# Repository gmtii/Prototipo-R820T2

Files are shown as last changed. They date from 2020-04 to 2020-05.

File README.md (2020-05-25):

Proyecto 'breakout' de un R820T2 más un QSD para obtener salida IQ directamente a la tarjeta de sonido del PC. La idea es experimentar con el R820T2 y un QSD cuya frecuencia de refencia es 4X a la de demodulación, generada por un Si5351. 

El proyecto contiene:

- Carpeta KICAD: esquemas y PCB directos para generar gerbers.

- Carpeta r820t2: código Arduino para controla el R820T2 y Si5351.

+ Existe un modo consola de comandos serial para controlar los registros del R820T2 directamente y experiemntar.

+ Modo CAT para controlar la frecuencia de sintonía a través de OMNIRIG y el HDSDR por ejemplo.

Los principales aspectos del diseño son:

- El microcontrolador que usemos debe ser 3.3V. 
- El código inicia el R820T2 mediante protocolo I2C. El led, pin 13, y la salida por el puerto serie nos dan indicación del proceso de inicio.
- La parte LOOP consiste en una librería CAT para controlar la frecuencia de sintonía mediante el PC, como por ejemplo el OMNIRIG y el HDSDR.

El principio de hardware es:

- La salida del R820T2 se fija en 5 MHz. El tuner hace un proceso de mezcla de la entrada RF, y la frecuencia de sintonía aparecerá en su salida en esos 5 MHz.
- Se emplea la salida CLKOUT del R820T2, como entrada para un Si5351. Lo ideal es usar un cristal de 25 Mhz en el R820T2.
- Se programa la salida del Si5351 CLK2 a 20 Mhz, que será la entrada del demodulador QSD. Esto realmente es un 'exceso' pero la idea es experimentar con el Si5351 también. Bastaría con instalar un TCXO de 20Mhz al R820T2 para tener exactamente la frecuencia necesaria de demodulación en el QSD, esto es 5 Mhz. Este TCXO sería precisamente el U1. 
- La conversión tiene lugar justo en esos 20MHz/4, esto es, 5 Mhz, justo la salida del R820T2.
- La salida IQ es pues en banda base y directamente aplicable a la tarjeta de sonido del PC. Es recomendable ajustar la entrada a 192 Khz para poder demodular WFM correctamente.
- Con cualquier software que soporte la tarjeta de sonido como entrada, SDR#, o HDSDR, por ejemplo, nos permitirá ver el espectro y demodular la señal resultante.

Modelo 3D de la placa PCB mediante KICAD:

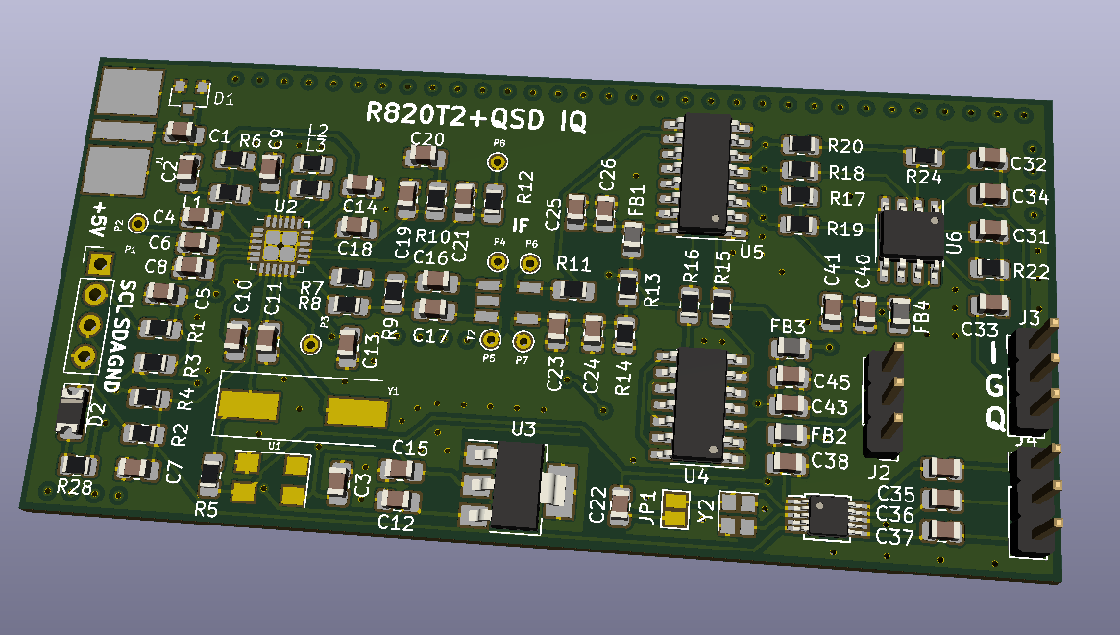
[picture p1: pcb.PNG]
pcb


El proyecto está basado en fuentes como:

Driver del kernel linux del R820T2 ofrecido bajo licencia GPL.
Datasheet del R820T2.
Breakout y fuentes del proyecto del R820T2 de Eric Brombaugh https://github.com/emeb/r820t2/. Licencia MIT.

Esteban EA8DGL estebanjbs < at > gmail.com

Breakout project of an R820T2 plus a QSD to get IQ output directly to the PC sound card. The idea is to experiment with the R820T2 and a QSD whose reference frequency is 4X that of demodulation, generated by a Si5351.

The project contains:

- KICAD folder: diagrams and direct PCBs to generate gerbers.

- r820t2 folder: Arduino code to control the R820T2 and Si5351.

+ There is a serial command console mode to control the registers of the R820T2 directly and experiment.

+ CAT mode to control the tuning frequency through OMNIRIG and HDSDR for example.

The main aspects of the design are:

- The microcontroller that we use must be 3.3V.
- The code starts the R820T2 using the I2C protocol. The led, pin 13, and the output through the serial port give us an indication of the startup process.
- The LOOP part consists of a CAT library to control the tuning frequency through the PC, such as OMNIRIG and HDSDR.

The hardware principle is:

- The R820T2's output is fixed at 5 MHz. The tuner does a process of mixing the RF input, and the tuning frequency will appear at its output at those 5 MHz.
- The CLKOUT output of the R820T2 is used as input for a Si5351. Ideally, use a 25Mhz crystal on the R820T2.
- The output of Si5351 CLK2 is programmed at 20 Mhz, which will be the input of the QSD demodulator. This really is 'overkill' but the idea is to experiment with the Si5351 as well. It would be enough to install a 20Mhz TCXO to the R820T2 to have exactly the necessary demodulation frequency in the QSD, this is 5 Mhz. This TCXO would be precisely U1.
- The conversion takes place right at those 20MHz / 4, that is, 5Mhz, just the output of the R820T2.
- The IQ output is thus in baseband and directly applicable to the PC sound card. It is recommended to set the input to 192 Khz in order to demodulate WFM correctly.
- With any software that supports the sound card as input, SDR #, or HDSDR, for example, it will allow us to see the spectrum and demodulate the resulting signal.

3D model of the PCB board using KICAD:

! [pcb] (pcb.PNG)

The project is based on sources such as:

R820T2 Linux kernel driver offered under the GPL license.
Datasheet of the R820T2.
Breakout and sources for Eric Brombaugh's R820T2 project https://github.com/emeb/r820t2/. MIT license.

Esteban EA8DGL estebanjbs <at> gmail.com

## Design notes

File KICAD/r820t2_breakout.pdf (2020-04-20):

r820t2_breakout

Id Designator | Package | Quantity
1 REF** | SolderWirePad_1x01_Drill0.8mm | 1
2 J4,J2 | PinHeader_1x03_P2.54mm_Vertical | 2
3 Y2 | Crystal_SMD_2520-4Pin_2.5x2.0mm | 1
4 JP1 | SolderJumper-2_P1.3mm_Open_Pad1.0x1.5mm | 1
5 C38,C22,C43,C40,C37,C36,C35,C25,C23 C_0805_2012Metric | 9
6 C4,C9,C8,C13,C21,C18,C17,C16,C14,C3 C_0805_2012Metric_Pad1.15x1.40mm_HandSolder | 10
7 C6 | C_0805_2012Metric_Pad1.15x1.40mm_HandSolder | 1
8 C2,C19 | C_0805_2012Metric_Pad1.15x1.40mm_HandSolder | 2
9 C1 | C_0805_2012Metric_Pad1.15x1.40mm_HandSolder | 1
10 R22,R26,R25 | R_0805_2012Metric | 3
11 RV1 | Potentiometer_Bourns_3214W_Vertical | 1
12 J3 | PinHeader_1x03_P2.54mm_Vertical | 1
13 U5 | SOIC-16_3.9x9.9mm_P1.27mm | 1
14 R24 | R_0805_2012Metric | 1
15 R15,R16 | R_0805_2012Metric | 2
16 U4 | SOIC-14_3.9x8.7mm_P1.27mm | 1
17 R11,R5 | R_0805_2012Metric_Pad1.15x1.40mm_HandSolder | 2
18 P4,P2,P3,P5,P6,P7,P8 | PINTST | 7
19 C11,C7,C5,C10 | C_0805_2012Metric_Pad1.15x1.40mm_HandSolder | 4
20 R4,R3 | R_0805_2012Metric_Pad1.15x1.40mm_HandSolder | 2
21 R2,R1,R8,R7 | R_0805_2012Metric_Pad1.15x1.40mm_HandSolder | 4
22 U7 | MSOP-10_3x3mm_P0.5mm | 1
23 U6 | SOIC-8_3.9x4.9mm_P1.27mm | 1
24 R28 | R_0805_2012Metric | 1
25 R20,R19,R18,R17 | R_0805_2012Metric | 4
26 R14,R13 | R_0805_2012Metric | 2
27 R12 | R_0805_2012Metric_Pad1.15x1.40mm_HandSolder | 1
28 R10 | R_0805_2012Metric_Pad1.15x1.40mm_HandSolder | 1
29 R9 | R_0805_2012Metric_Pad1.15x1.40mm_HandSolder | 1
30 R6 | R_0805_2012Metric_Pad1.15x1.40mm_HandSolder | 1
31 L3,L2 | R_0805_2012Metric_Pad1.15x1.40mm_HandSolder | 2
32 L1 | R_0805_2012Metric_Pad1.15x1.40mm_HandSolder | 1
33 FB4,FB3,FB2,FB1 | L_0805_2012Metric | 4
34 D2 | D_1206_3216Metric | 1
35 C45,C41,C26,C24 | C_0805_2012Metric | 4
36 C34,C33 | C_0805_2012Metric | 2
37 C32,C31 | C_0805_2012Metric | 2
38 C30,C29,C28,C27 | C_0805_2012Metric | 4
39 C20 | C_0805_2012Metric_Pad1.15x1.40mm_HandSolder | 1
40 C15,C12 | C_0805_2012Metric_Pad1.15x1.40mm_HandSolder | 2
41 D1 | SOT-23 | 1
42 P1 | Pin_Header_Straight_1x04_Pitch2.54mm | 1
43 T2 | Pulse_SMD_Balun | 1
44 U1 | Crystal_SMD_Abracon_ABM3C-4pin_5.0x3.2mm | 1
45 U3 | SOT-223 | 1
46 Y1 | XTAL 2520 SMD 25 Mhz | 1
47 J1 | SMA_END | 1
48 U2 | QFN-24-1EP_4x4mm_Pitch0.5mm_extended_pad | 1

r820t2_breakout

Designation | Supplier and ref
SolderWirePad_1x01_Drill0.8mm
CLK Source
Crystal_GND24
SolderJumper_2_Open
100nF
0.1uf
1uf
330pf
0.01uf
10k
5k
Conn_01x03_Male
SN74CBT3253
8.2k
0
74HC74
0
CONN_01X01
27pf
4k7
220
Si5351A-B-GT
LT6234
512
100
5.6k
10k
1k8
DNI
10
150nh
8.2nH
Ferrite_Bead
LED
4.7uF
2.2uF
330p
33nF
6800pf
10uf
BAV99
CONN_01X04
TRANSFO4
TWEAALSANF-28.800000
LD1117S33CTR
25MHz
SMA
R820T2

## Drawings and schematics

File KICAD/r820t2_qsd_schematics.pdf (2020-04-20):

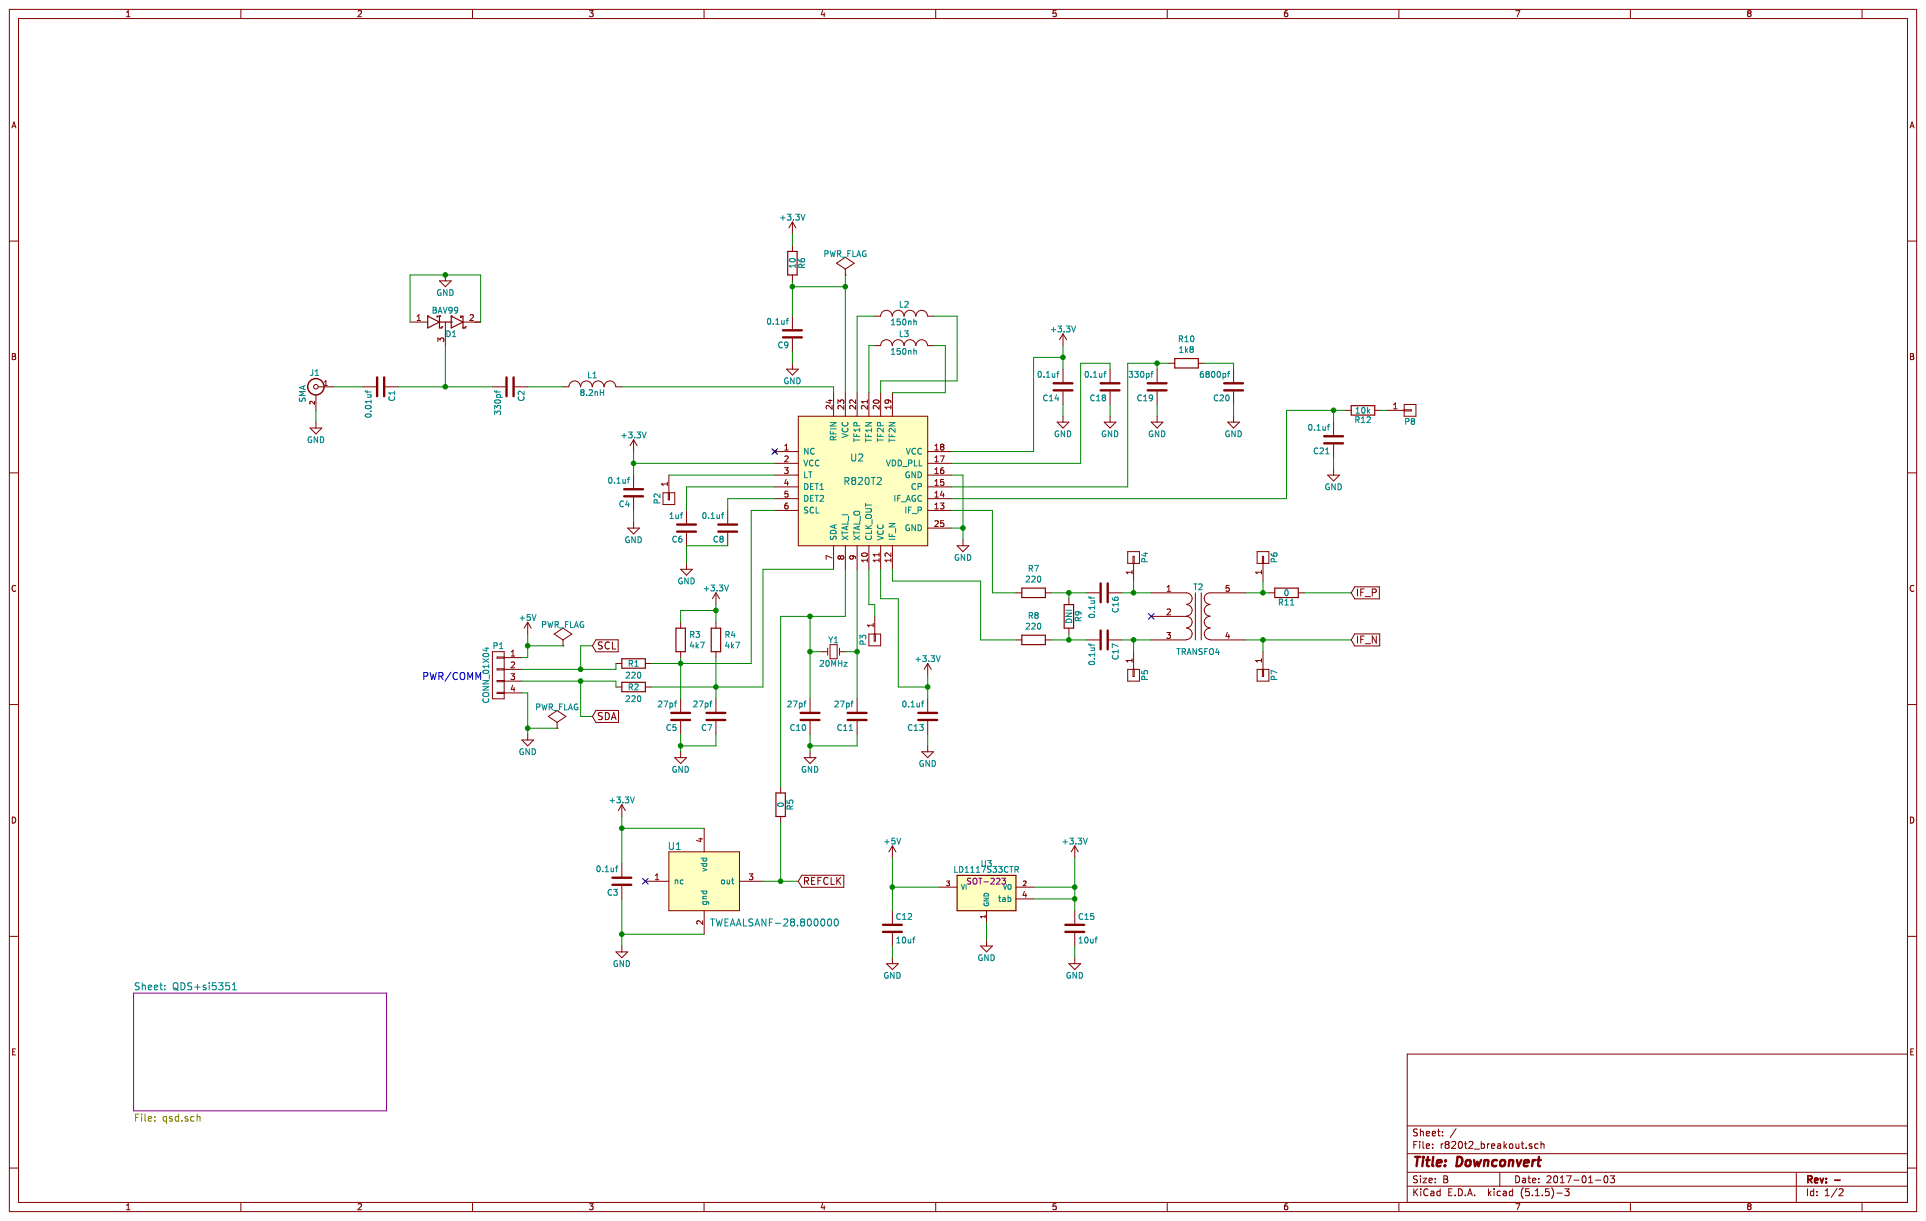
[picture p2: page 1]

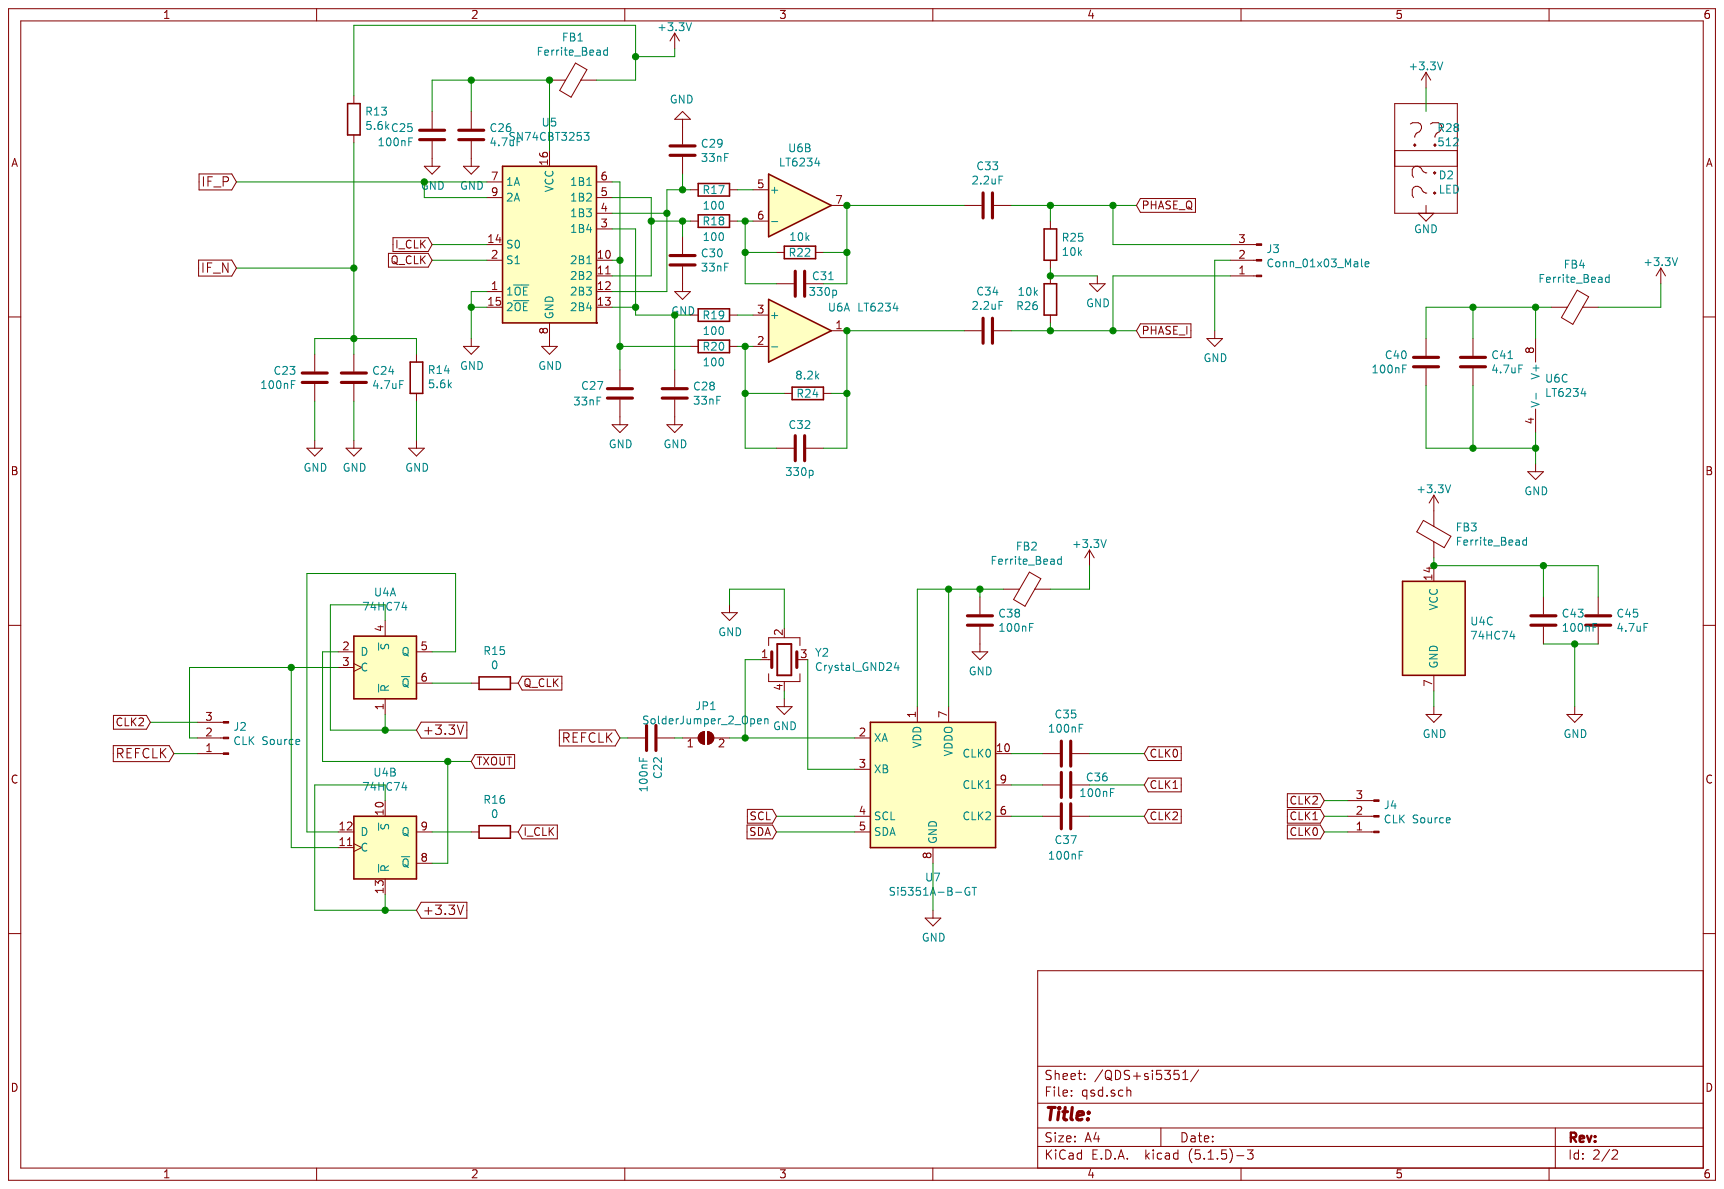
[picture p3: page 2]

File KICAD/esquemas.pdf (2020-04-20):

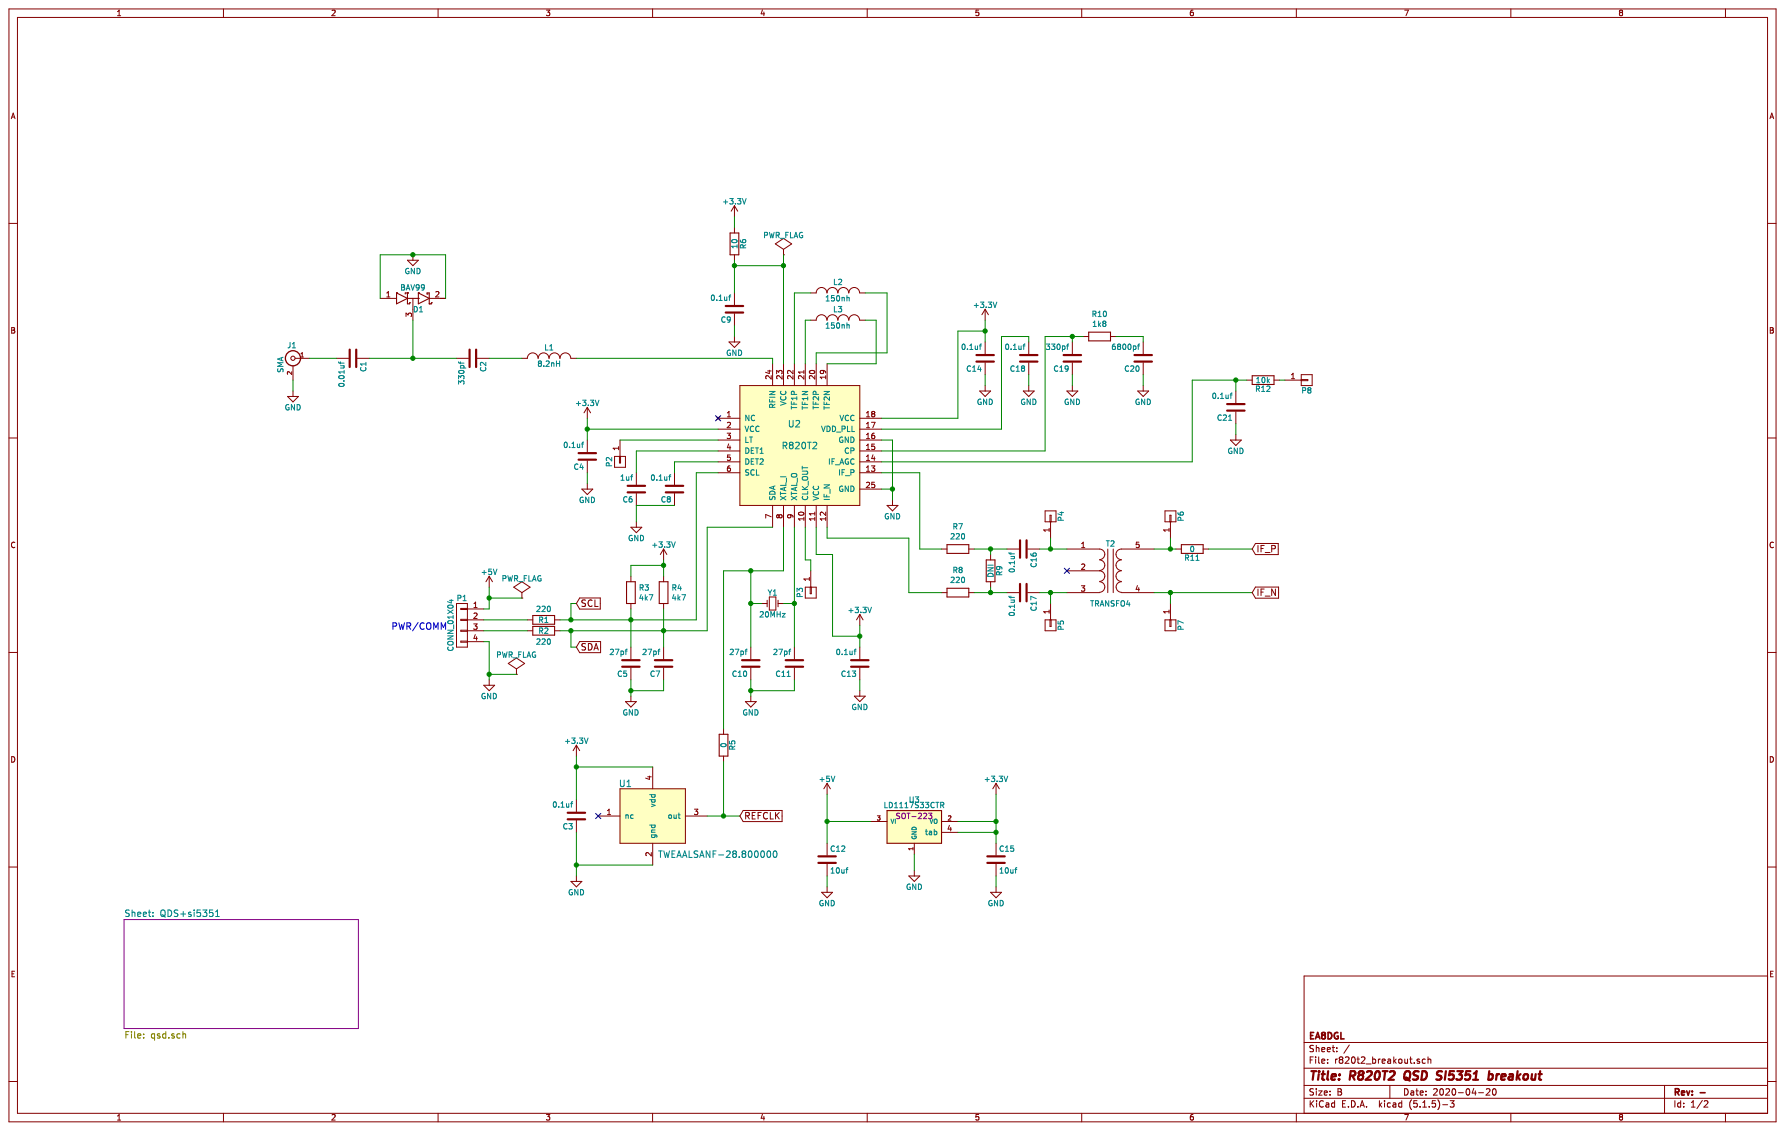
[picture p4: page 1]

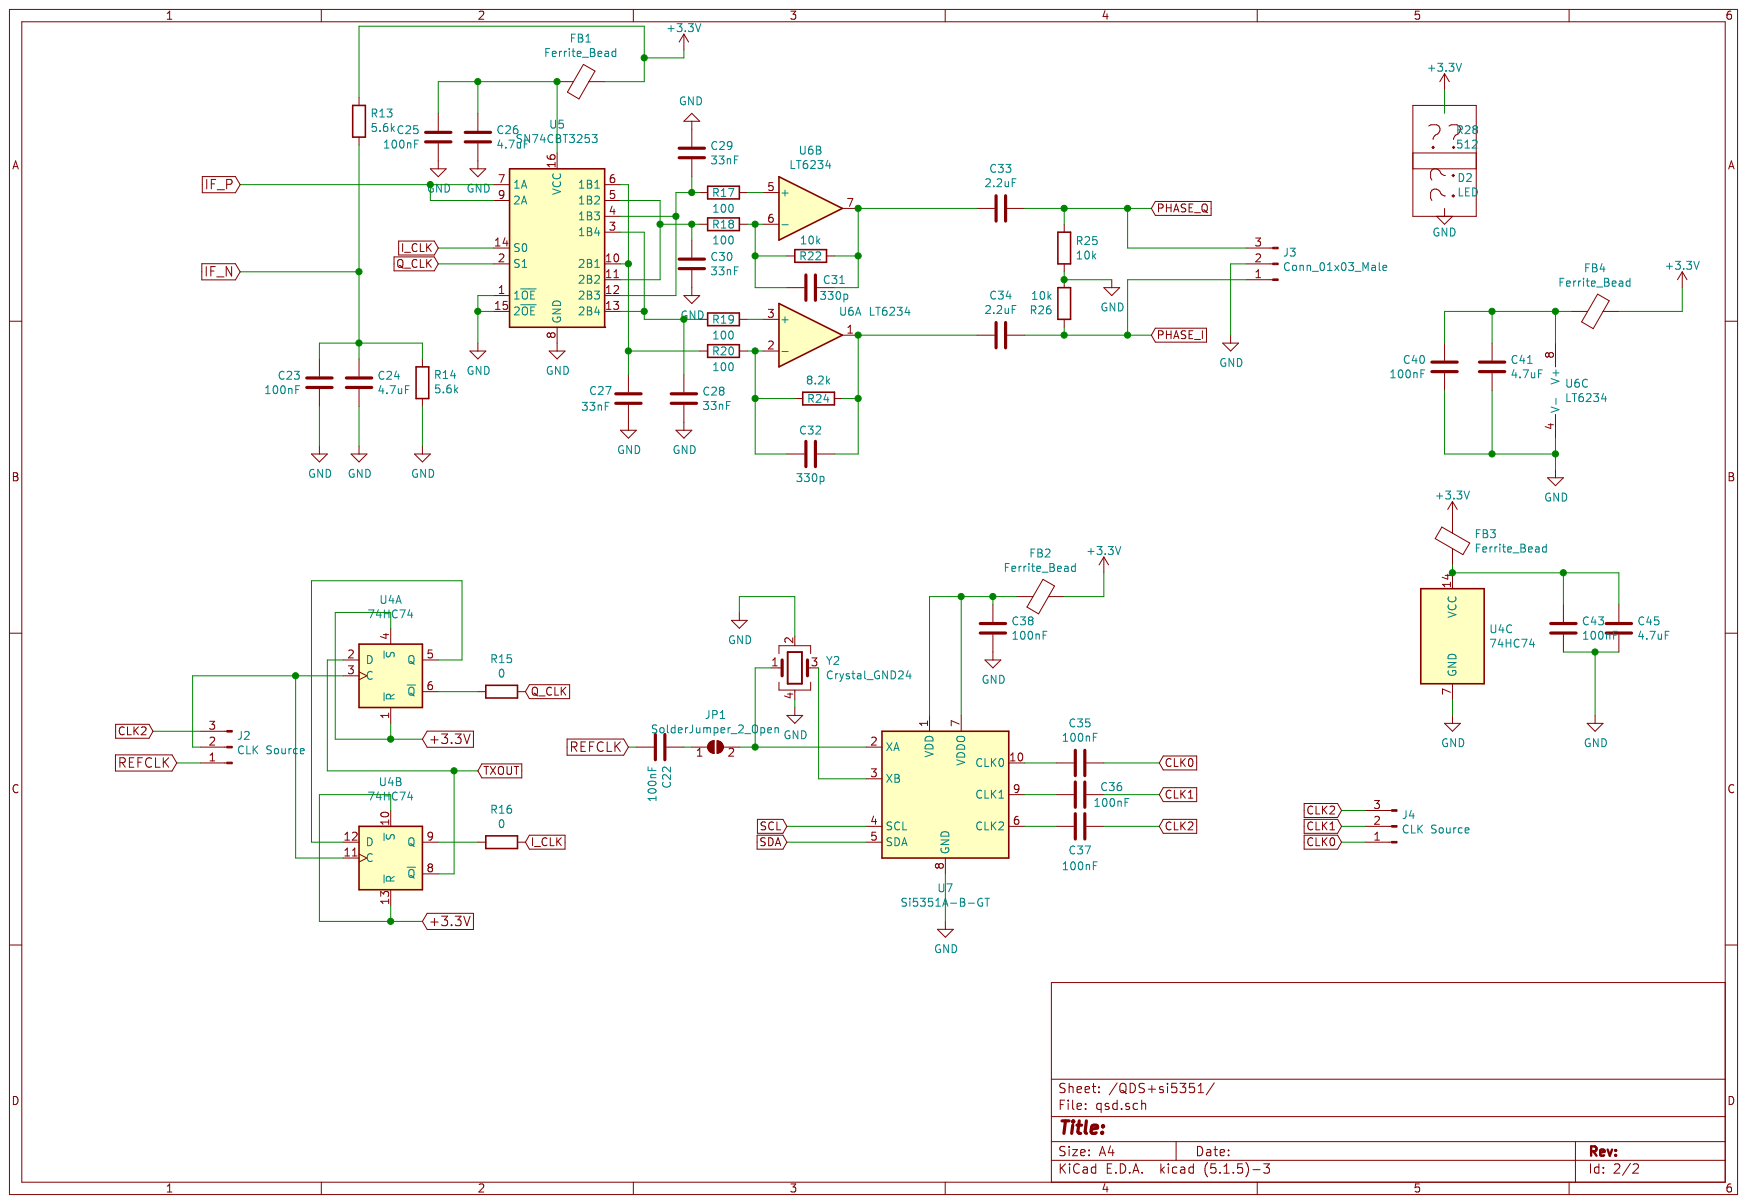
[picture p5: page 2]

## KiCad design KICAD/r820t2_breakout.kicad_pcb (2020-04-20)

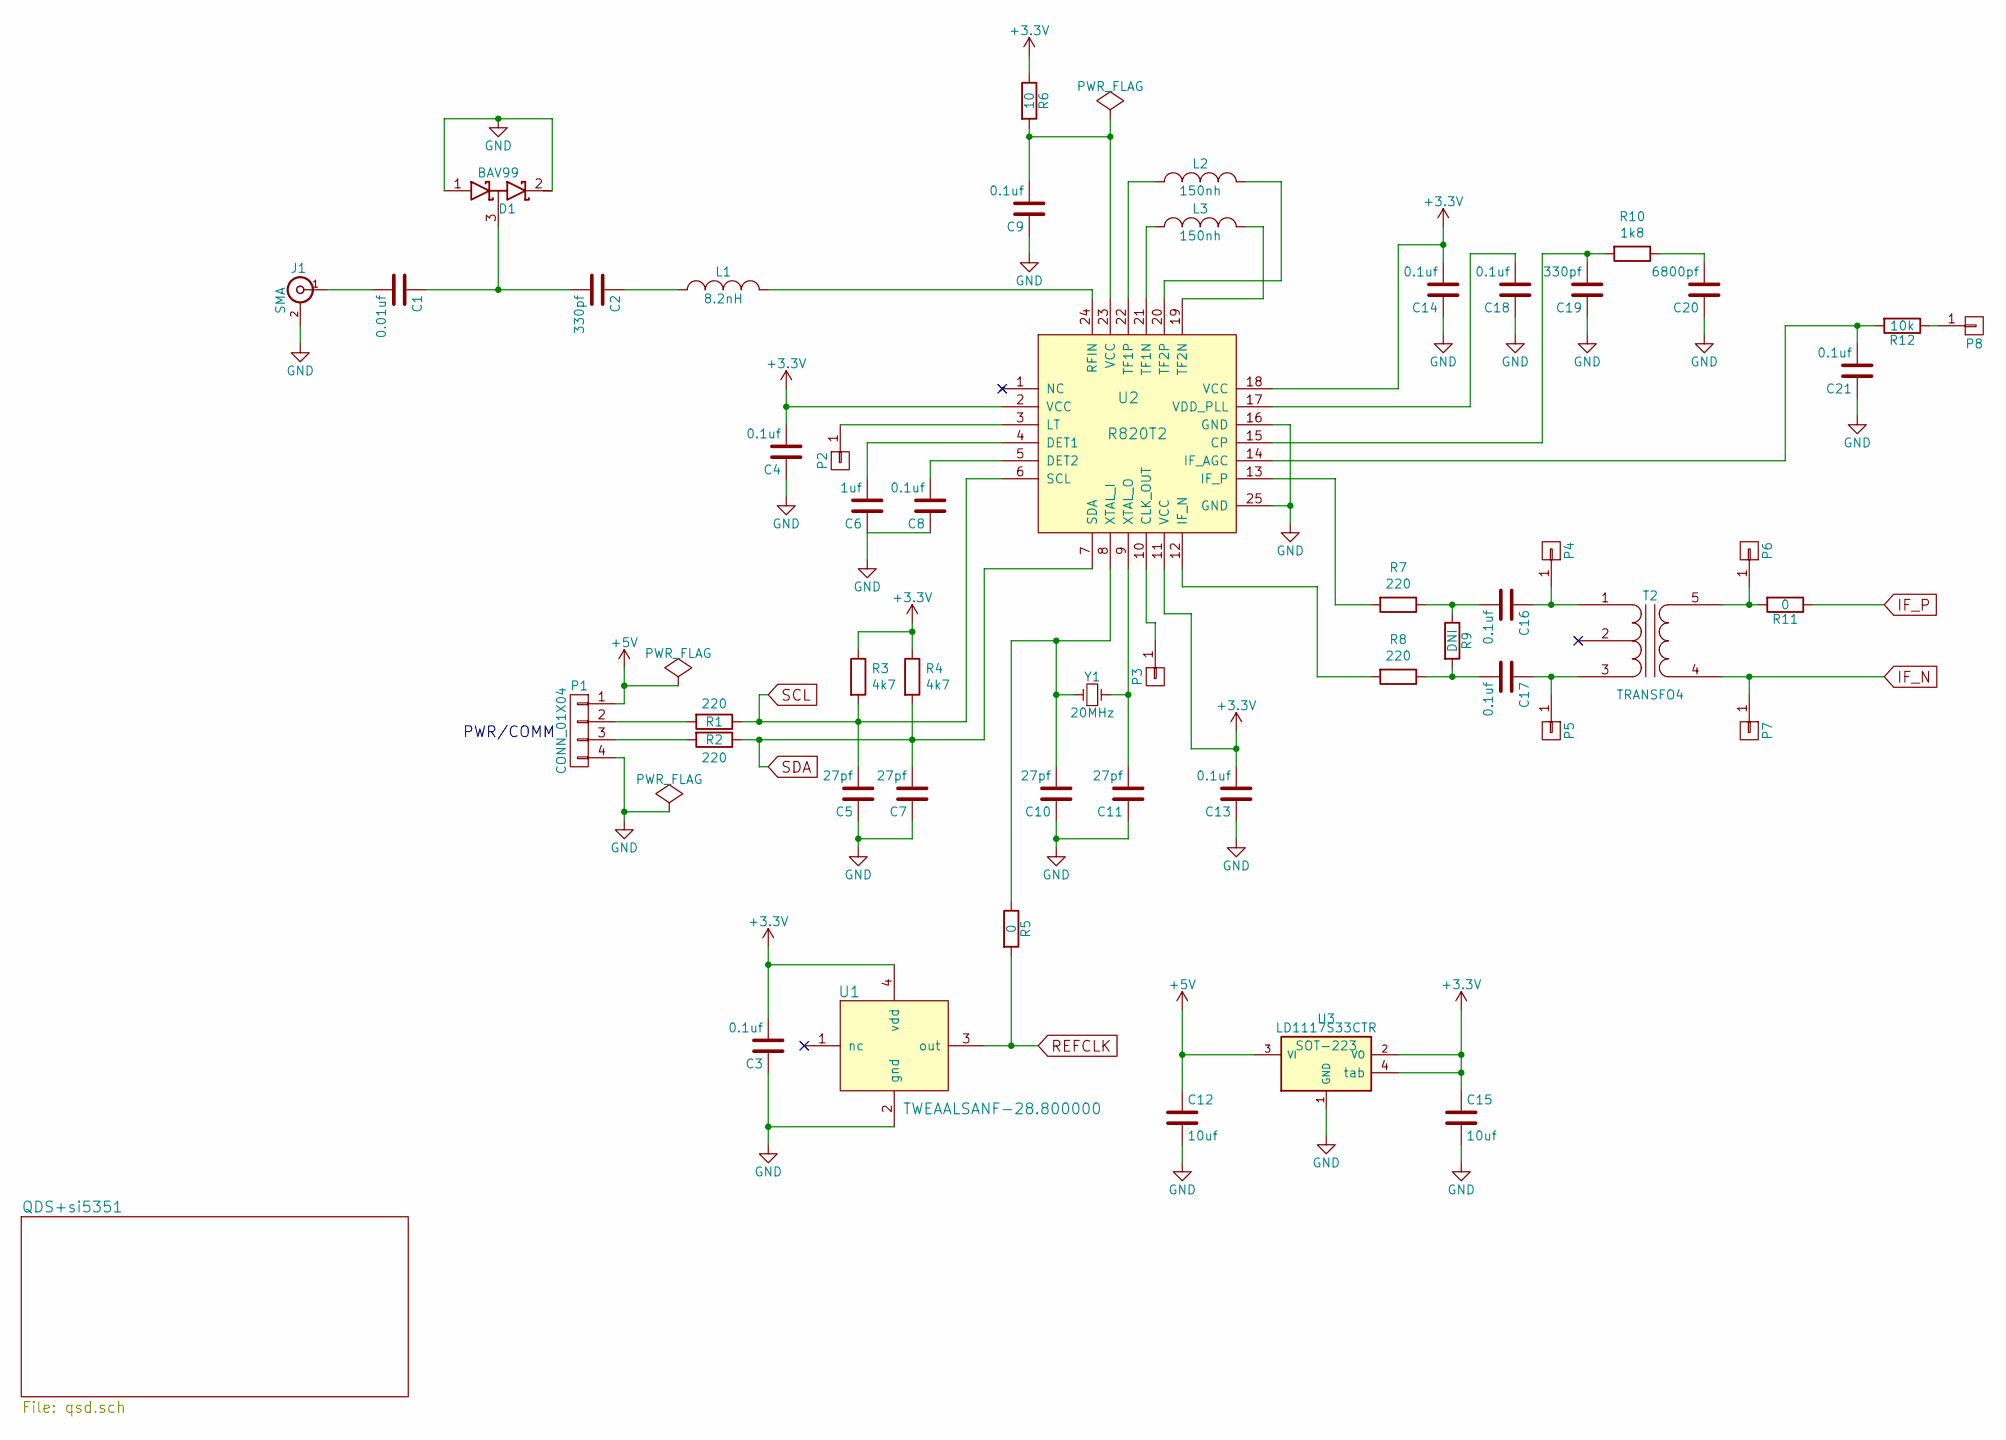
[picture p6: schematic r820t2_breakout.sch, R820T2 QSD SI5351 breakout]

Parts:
C1: 0.01uf; C_0805_2012Metric_Pad1.15x1.40mm_HandSolder
C2, C19: 330pf; C_0805_2012Metric_Pad1.15x1.40mm_HandSolder
C3, C4, C8, C9, C13, C14, C16, C17, C18, C21: 0.1uf; C_0805_2012Metric_Pad1.15x1.40mm_HandSolder
C5, C7, C10, C11: 27pf; C_0805_2012Metric_Pad1.15x1.40mm_HandSolder
C6: 1uf; C_0805_2012Metric_Pad1.15x1.40mm_HandSolder
C12, C15: 10uf; C_0805_2012Metric_Pad1.15x1.40mm_HandSolder
C20: 6800pf; C_0805_2012Metric_Pad1.15x1.40mm_HandSolder
D1: BAV99; SOT-23
J1: SMA; SMA_END
L1: 8.2nH; R_0805_2012Metric_Pad1.15x1.40mm_HandSolder
L2, L3: 150nh; R_0805_2012Metric_Pad1.15x1.40mm_HandSolder
P1: CONN_01X04; Pin_Header_Straight_1x04_Pitch2.54mm
P2, P3, P4, P5, P6, P7, P8: CONN_01X01; PINTST
R1, R2, R7, R8: 220; R_0805_2012Metric_Pad1.15x1.40mm_HandSolder
R3, R4: 4k7; R_0805_2012Metric_Pad1.15x1.40mm_HandSolder
R5, R11: 0; R_0805_2012Metric_Pad1.15x1.40mm_HandSolder
R6: 10; R_0805_2012Metric_Pad1.15x1.40mm_HandSolder
R9: DNI; R_0805_2012Metric_Pad1.15x1.40mm_HandSolder
R10: 1k8; R_0805_2012Metric_Pad1.15x1.40mm_HandSolder
R12: 10k; R_0805_2012Metric_Pad1.15x1.40mm_HandSolder
T2: TRANSFO4; Pulse_SMD_Balun
U1: TWEAALSANF-28.800000; Crystal_SMD_Abracon_ABM3C-4pin_5.0x3.2mm
U2: R820T2; QFN-24-1EP_4x4mm_P0.5mm_EP2.65x2.65mm_ThermalVias
U3: LD1117S33CTR; SOT-223
Y1: 20MHz; Crystal_SMD_HC49-SD

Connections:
+3V3: C3.2, C4.2, C13.2, C14.2, C15.1, R3.1, R4.1, R6.1, U1.4 (vdd), U2.2 (VCC), U2.11 (VCC), U2.18 (VCC), U3.2 (VO), U3.4 (tab); also elsewhere on the board
+5V: C12.1, P1.1, U3.3 (VI)
GND: C3.1, C4.1, C5.1, C6.1, C7.1, C8.1, C9.1, C10.1, C11.1, C12.2, C13.1, C14.1, C15.2, C18.1, C19.1, C20.1, C21.1, D1.1 (A), D1.2 (K), J1.2 (Ext), P1.4, U1.2 (gnd), U2.16 (GND), U2.25 (GND), U3.1 (GND); also elsewhere on the board
IF_N: P7.1, T2.4 (S1); also elsewhere on the board
IF_P: R11.1; also elsewhere on the board
unnamed: C1.1, C2.2, D1.3 (common)
unnamed: C1.2, J1.1 (In)
unnamed: C2.1, L1.1
unnamed: C6.2, U2.4 (DET1)
unnamed: C8.2, U2.5 (DET2)
unnamed: C9.2, R6.2, U2.23 (VCC)
unnamed: C10.2, R5.1, U2.8 (XTAL_I), Y1.1
unnamed: C11.2, U2.9 (XTAL_O), Y1.2
unnamed: C16.1, P4.1, T2.1 (PR1)
unnamed: C16.2, R7.1, R9.1
unnamed: C17.1, P5.1, T2.3 (PR2)
unnamed: C17.2, R8.1, R9.2
unnamed: C18.2, U2.17 (VDD_PLL)
unnamed: C19.2, R10.2, U2.15 (CP)
unnamed: C20.2, R10.1
unnamed: C21.2, R12.2, U2.14 (IF_AGC)
unnamed: L1.2, U2.24 (RFIN)
unnamed: L2.1, U2.20 (TF2P)
unnamed: L2.2, U2.22 (TF1P)
unnamed: L3.1, U2.19 (TF2N)
unnamed: L3.2, U2.21 (TF1N)
unnamed: P1.2, R1.2
unnamed: P1.3, R2.2
unnamed: P2.1, U2.3 (LT)
unnamed: P3.1, U2.10 (CLK_OUT)
unnamed: P6.1, R11.2, T2.5 (S2)
unnamed: P8.1, R12.1
unnamed: R7.2, U2.13 (IF_P)
unnamed: R8.2, U2.12 (IF_N)
REFCLK: R5.2, U1.3 (out); also elsewhere on the board
SCL: C5.2, R1.1, R3.2, U2.6 (SCL); also elsewhere on the board
SDA: C7.2, R2.1, R4.2, U2.7 (SDA); also elsewhere on the board

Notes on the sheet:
PWR/COMM

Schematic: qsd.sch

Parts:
C22, C23, C25, C35, C36, C37, C38, C40, C43: 100nF; C_0805_2012Metric
C24, C26, C41, C45: 4.7uF; C_0805_2012Metric
C27, C28, C29, C30: 33nF; C_0805_2012Metric
C31, C32: 330p; C_0805_2012Metric
C33, C34: 2.2uF; C_0805_2012Metric
D2: LED; D_1206_3216Metric
FB1, FB2, FB3, FB4: Ferrite_Bead; L_0805_2012Metric
J2, J4: CLK Source; PinHeader_1x03_P2.54mm_Vertical
J3: Conn_01x03_Male; PinHeader_1x03_P2.54mm_Vertical
JP1: SolderJumper_2_Open; SolderJumper-2_P1.3mm_Open_Pad1.0x1.5mm
R13, R14: 5.6k; R_0805_2012Metric
R15, R16: 0; R_0805_2012Metric
R17, R18, R19, R20: 100; R_0805_2012Metric
R22, R25, R26: 10k; R_0805_2012Metric
R24: 8.2k; R_0805_2012Metric
R28: 512; R_0805_2012Metric
U4: 74HC74; SOIC-14_3.9x8.7mm_P1.27mm
U5: SN74CBT3253; SOIC-16_3.9x9.9mm_P1.27mm
U6: LT6234; SOIC-8_3.9x4.9mm_P1.27mm
U7: Si5351A-B-GT; MSOP-10_3x3mm_P0.5mm
Y2: Crystal_GND24; Crystal_SMD_2520-4Pin_2.5x2.0mm

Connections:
+3.3V: U4.1 (~R), U4.4 (~S), U4.10 (~S), U4.13 (~R)
+3V3: FB1.1, FB2.1, FB3.1, FB4.1, R13.2, R28.1; also elsewhere on the board
CLK0: C35.1, J4.1
CLK1: C36.1, J4.2
CLK2: C37.1, J2.3, J4.3
GND: C23.2, C24.2, C25.2, C26.2, C27.2, C28.2, C29.1, C30.2, C38.2, C40.2, C41.2, C43.2, C45.2, D2.1, J3.2, R14.1, R25.2, R26.2, U4.7 (GND), U5.1 (1~OE), U5.8 (GND), U5.15 (2~OE), U6.4 (V-), U7.8 (GND), Y2.2, Y2.4; also elsewhere on the board
IF_N: C23.1, C24.1, R13.1, R14.2; also elsewhere on the board
IF_P: U5.7 (1A), U5.9 (2A); also elsewhere on the board
I_CLK: R16.1, U5.14 (S0)
unnamed: C22.1, JP1.1 (A)
unnamed: C25.1, C26.1, FB1.2, U5.16 (VCC)
unnamed: C27.1, R20.2, U5.6 (1B1), U5.10 (2B1)
unnamed: C28.1, R19.2, U5.3 (1B4), U5.13 (2B4)
unnamed: C29.2, R17.2, U5.4 (1B3), U5.12 (2B3)
unnamed: C30.1, R18.2, U5.5 (1B2), U5.11 (2B2)
unnamed: C31.1, C33.2, R22.1, U6.7
unnamed: C31.2, R18.1, R22.2, U6.6 (-)
unnamed: C32.1, C34.2, R24.1, U6.1
unnamed: C32.2, R20.1, R24.2, U6.2 (-)
unnamed: C35.2, U7.10 (CLK0)
unnamed: C36.2, U7.9 (CLK1)
unnamed: C37.2, U7.6 (CLK2)
unnamed: C38.1, FB2.2, U7.1 (VDD), U7.7 (VDDO)
unnamed: C40.1, C41.1, FB4.2, U6.8 (V+)
unnamed: C43.1, C45.1, FB3.2, U4.14 (VCC)
unnamed: D2.2, R28.2
unnamed: J2.2, U4.3 (C), U4.11 (C)
unnamed: JP1.2 (B), U7.2 (XA), Y2.1
unnamed: R15.2, U4.6 (~Q)
unnamed: R16.2, U4.9 (Q)
unnamed: R17.1, U6.5 (+)
unnamed: R19.1, U6.3 (+)
unnamed: U4.5 (Q), U4.12 (D)
unnamed: U7.3 (XB), Y2.3
PHASE_I: C34.1, J3.1, R26.1
PHASE_Q: C33.1, J3.3, R25.1
Q_CLK: R15.1, U5.2 (S1)
REFCLK: C22.2, J2.1; also elsewhere on the board
SCL: U7.4 (SCL); also elsewhere on the board
SDA: U7.5 (SDA); also elsewhere on the board
TXOUT: U4.2 (D), U4.8 (~Q)

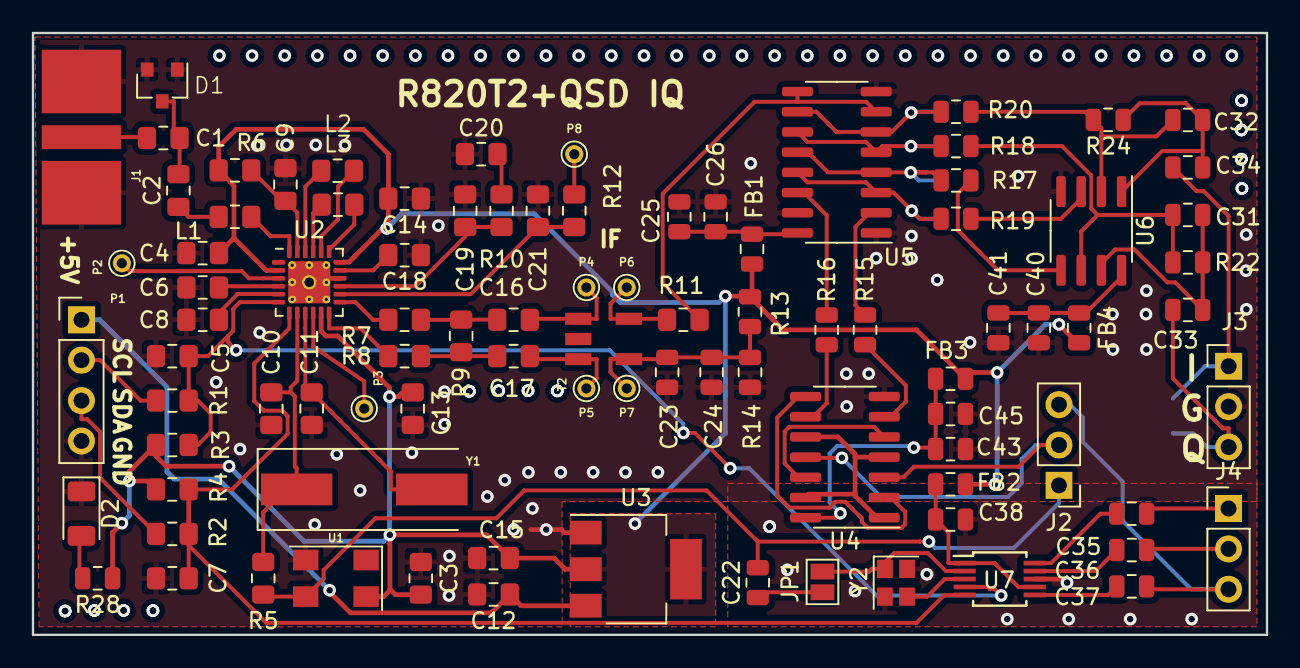
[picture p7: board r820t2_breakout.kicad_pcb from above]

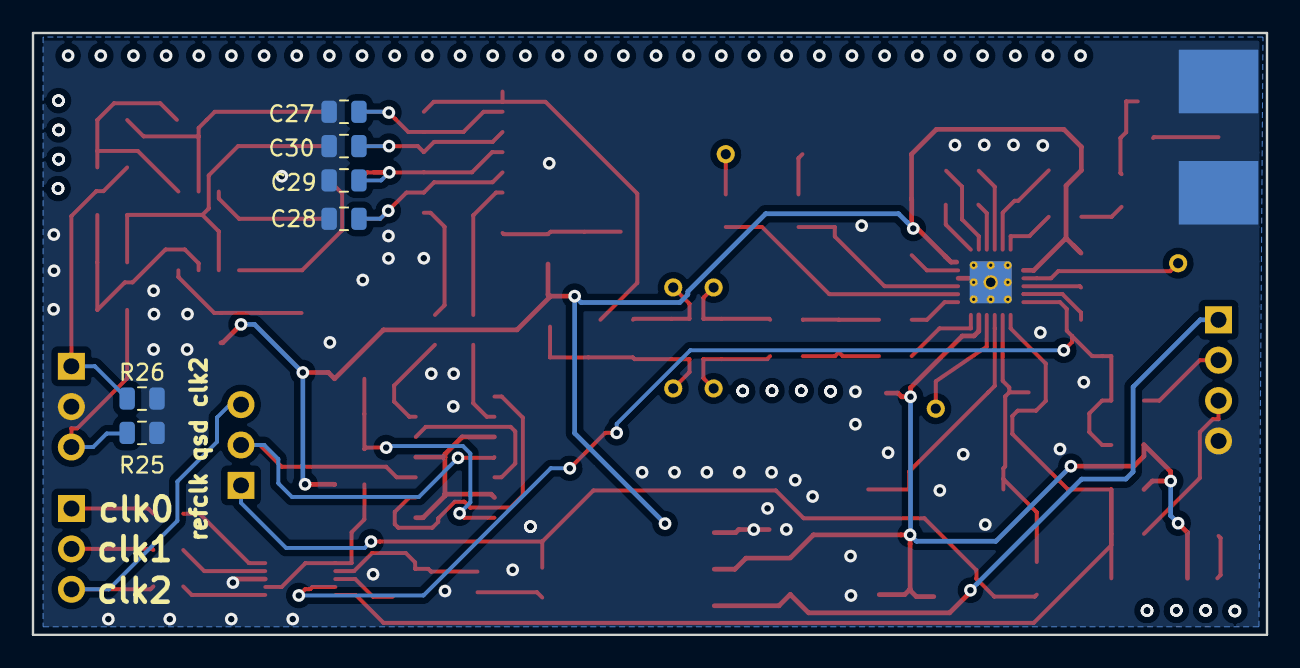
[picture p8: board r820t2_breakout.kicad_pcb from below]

Board: 2 copper layers, 77.6 x 37.8 mm, 99 parts (6 on the bottom side), 71 nets.

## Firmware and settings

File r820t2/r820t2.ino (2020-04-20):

/* 
	Prototipo R820T2+QSD con Si5351 
	Basado en drivers
    Copyright (C) 2020 EA8DGL

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
	*/


#include <Arduino.h>
#include <Wire.h>

#include "si5351.h"
#include "serial_cmd.h"

const int ledPin = 13;


#define SI5351_XTAL_FREQ  25000000

uint64_t target_freq = 2000000000ULL;
int32_t cal_factor = 10000;


Si5351 si5351;

void setup() {

  byte error;
  pinMode(ledPin, OUTPUT);

  Serial.begin(9600);
  Serial.flush();

  delay(2000);

  Wire.begin();

  Wire.beginTransmission(0x1A);
  error = Wire.endTransmission();

  if (error == 0)
  {
    Serial.println("I2C device found at address 0x1A");

    digitalWrite(ledPin, HIGH);
    delay(250);
    digitalWrite(ledPin, LOW);
    delay(250);
  }

  Wire.beginTransmission(0x60);
  error = Wire.endTransmission();

  if (error == 0)
  {
    Serial.println("I2C device found at address 0x60");

    digitalWrite(ledPin, HIGH);
    delay(250);
    digitalWrite(ledPin, LOW);
    delay(250);
    digitalWrite(ledPin, HIGH);
  }

  R820T2_init();

  delay(500);

  // Start on target frequency
  si5351.set_correction(cal_factor, SI5351_PLL_INPUT_XO);
  si5351.set_pll(SI5351_PLL_FIXED, SI5351_PLLA);


  si5351.init(SI5351_CRYSTAL_LOAD_0PF, SI5351_XTAL_FREQ, 0);
  si5351.set_freq(target_freq, SI5351_CLK2);
  si5351.output_enable(SI5351_CLK2, 1);

  si5351.update_status();

  delay(500);

  // I had near 0.7 Vpp CLKIN -> LOS=1 so it need to repeat init sequence.

  si5351.init(SI5351_CRYSTAL_LOAD_0PF, SI5351_XTAL_FREQ, 0);
  si5351.set_freq(target_freq, SI5351_CLK2);
  si5351.output_enable(SI5351_CLK2, 1);
  
  si5351.output_enable(SI5351_CLK0, 0);
  si5351.output_enable(SI5351_CLK1, 0);

  si5351.update_status();

  //tft.fillScreen(TFT_BLACK);
  //tft.setTextColor(TFT_WHITE, TFT_BLACK);
  //tft.setTextFont(3);

}

static void flush_input(void)
{
  while (Serial.available() > 0)
    Serial.read();
}

// ;Loop to check for FT 575 Yaesu compatible CAT commands.

void loop()
{
  // Serial_CMD();  // Uncomment to enable R820T2 console.
  checkCAT(); 

}

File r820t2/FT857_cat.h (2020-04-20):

/**
 * The CAT protocol is used by many radios to provide remote control to comptuers through
 * the serial port.
 * 
 * This is very much a work in progress. Parts of this code have been liberally
 * borrowed from other GPLicensed works like hamlib.
 * 
 * WARNING : This is an unstable version and it has worked with fldigi, 
 * it gives time out error with WSJTX 1.8.0  
 */


/** 
 *  The second set of 16 pins on the Raduino's bottom connector are have the three clock outputs and the digital lines to control the rig.
 *  This assignment is as follows :
 *    Pin   1   2    3    4    5    6    7    8    9    10   11   12   13   14   15   16
 *         GND +5V CLK0  GND  GND  CLK1 GND  GND  CLK2  GND  D2   D3   D4   D5   D6   D7  
 *  These too are flexible with what you may do with them, for the Raduino, we use them to :
 *  - TX_RX line : Switches between Transmit and Receive after sensing the PTT or the morse keyer
 *  - CW_KEY line : turns on the carrier for CW
 */

#define TX_RX (7)
#define CW_TONE (6)
#define TX_LPF_A (5)
#define TX_LPF_B (4)
#define TX_LPF_C (3)
#define CW_KEY (2)

/**
 * These are the indices where these user changable settinngs are stored  in the EEPROM
 */
#define MASTER_CAL 0
#define LSB_CAL 4
#define USB_CAL 8
#define SIDE_TONE 12
//these are ids of the vfos as well as their offset into the eeprom storage, don't change these 'magic' values
#define VFO_A 16
#define VFO_B 20
#define CW_SIDETONE 24
#define CW_SPEED 28

//These are defines for the new features back-ported from KD8CEC's software
//these start from beyond 256 as Ian, KD8CEC has kept the first 256 bytes free for the base version
#define VFO_A_MODE  256 // 2: LSB, 3: USB
#define VFO_B_MODE  257

//values that are stroed for the VFO modes
#define VFO_MODE_LSB 2
#define VFO_MODE_USB 3

// handkey, iambic a, iambic b : 0,1,2f
#define CW_KEY_TYPE 358




//these are the two default USB and LSB frequencies. The best frequencies depend upon your individual taste and filter shape
#define INIT_USB_FREQ   (11996500l)
// limits the tuning and working range of the ubitx between 3 MHz and 30 MHz
#define LOWEST_FREQ   (100000l)
#define HIGHEST_FREQ (30000000l)

//we directly generate the CW by programmin the Si5351 to the cw tx frequency, hence, both are different modes
//these are the parameter passed to startTx
#define TX_SSB 0
#define TX_CW 1

char ritOn = 0;
char vfoActive = VFO_A;
int8_t meter_reading = 0; // a -1 on meter makes it invisible
unsigned long vfoA=7150000L, vfoB=14200000L, sideTone=800, usbCarrier;
char isUsbVfoA=0, isUsbVfoB=1;
unsigned long ritRxFrequency, ritTxFrequency;  //frequency is the current frequency on the dial
extern uint32_t  r820t_freq;

uint32_t frequency = r820t_freq;

unsigned long firstIF =   45000000L;

//these are variables that control the keyer behaviour
int cwSpeed = 100; //this is actuall the dot period in milliseconds
extern int32_t calibration;
byte cwDelayTime = 60;
bool Iambic_Key = true;
#define IAMBICB 0x10 // 0 for Iambic A, 1 for Iambic B
unsigned char keyerControl = IAMBICB;


/**
 * Raduino needs to keep track of current state of the transceiver. These are a few variables that do it
 */
boolean txCAT = false;        //turned on if the transmitting due to a CAT command
char inTx = 0;                //it is set to 1 if in transmit mode (whatever the reason : cw, ptt or cat)
char splitOn = 0;             //working split, uses VFO B as the transmit frequency, (NOT IMPLEMENTED YET)
char keyDown = 0;             //in cw mode, denotes the carrier is being transmitted
char isUSB = 0;               //upper sideband was selected, this is reset to the default for the 
                              //frequency when it crosses the frequency border of 10 MHz
byte menuOn = 0;              //set to 1 when the menu is being displayed, if a menu item sets it to zero, the menu is exited
unsigned long cwTimeout = 0;  //milliseconds to go before the cw transmit line is released and the radio goes back to rx mode
unsigned long dbgCount = 0;   //not used now
unsigned char txFilter = 0;   //which of the four transmit filters are in use
boolean modeCalibrate = false;//this mode of menus shows extended menus to calibrate the oscillators and choose the proper
       
static unsigned long rxBufferArriveTime = 0;
static byte rxBufferCheckCount = 0;
#define CAT_RECEIVE_TIMEOUT 100
static byte cat[5]; 
static byte insideCat = 0; 

//for broken protocol
#define CAT_RECEIVE_TIMEOUT 100

#define CAT_MODE_LSB            0x00
#define CAT_MODE_USB            0x01
#define CAT_MODE_CW             0x02
#define CAT_MODE_CWR            0x03
#define CAT_MODE_AM             0x04
#define CAT_MODE_FM             0x08
#define CAT_MODE_DIG            0x0A
#define CAT_MODE_PKT            0x0C
#define CAT_MODE_FMN            0x88

#define ACK 0

unsigned int skipTimeCount = 0;

byte setHighNibble(byte b,byte v) {
  // Clear the high nibble
  b &= 0x0f;
  // Set the high nibble
  return b | ((v & 0x0f) << 4);
}

byte setLowNibble(byte b,byte v) {
  // Clear the low nibble
  b &= 0xf0;
  // Set the low nibble
  return b | (v & 0x0f);
}

byte getHighNibble(byte b) {
  return (b >> 4) & 0x0f;
}

byte getLowNibble(byte b) {
  return b & 0x0f;
}

// Takes a number and produces the requested number of decimal digits, staring
// from the least significant digit.  
//
void getDecimalDigits(unsigned long number,byte* result,int digits) {
  for (int i = 0; i < digits; i++) {
    // "Mask off" (in a decimal sense) the LSD and return it
    result[i] = number % 10;
    // "Shift right" (in a decimal sense)
    number /= 10;
  }
}

// Takes a frequency and writes it into the CAT command buffer in BCD form.
//
void writeFreq(unsigned long freq,byte* cmd) {
  // Convert the frequency to a set of decimal digits. We are taking 9 digits
  // so that we can get up to 999 MHz. But the protocol doesn't care about the
  // LSD (1's place), so we ignore that digit.
  byte digits[9];
  getDecimalDigits(freq,digits,9);
  // Start from the LSB and get each nibble 
  cmd[3] = setLowNibble(cmd[3],digits[1]);
  cmd[3] = setHighNibble(cmd[3],digits[2]);
  cmd[2] = setLowNibble(cmd[2],digits[3]);
  cmd[2] = setHighNibble(cmd[2],digits[4]);
  cmd[1] = setLowNibble(cmd[1],digits[5]);
  cmd[1] = setHighNibble(cmd[1],digits[6]);
  cmd[0] = setLowNibble(cmd[0],digits[7]);
  cmd[0] = setHighNibble(cmd[0],digits[8]);  
}
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

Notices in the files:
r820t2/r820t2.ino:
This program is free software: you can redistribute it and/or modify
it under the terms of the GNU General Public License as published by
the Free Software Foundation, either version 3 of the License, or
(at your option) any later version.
